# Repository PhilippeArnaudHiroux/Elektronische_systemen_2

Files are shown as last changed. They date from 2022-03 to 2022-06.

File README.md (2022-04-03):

# Elektronische_systemen_2

## Multisim

Lichtspectrum analyse sensor

1. **De onderdelen op de schakeling**
- XWG1 en XSC1 stellen de Esp32 voor
- U1 is de demultiplexer
- Q… zijn de fototransistors
- U… zijn invertors (zijn niet nodig op de PCB)
- R zijn de weerstanden die het licht voorstellen

1. **Hoe werkt de schakeling**
   1. *XWG1*

De XWG1 fungeert als een word generator. Deze gaat binaire getallen van 000 tot 111 uitsturen naar de demultiplexer. Dit is de output van de Esp32.



1. *De demultiplexer*

De demultiplexer gaat de binaire woorden van de word generator ontvangen op zijn 4 ingangen. Vervolgens gaat deze hiermee zijn uitgangen aansturen. Op elke uitgang is er een fototransistor aangesloten. 

1. *De invertors*

In Multisim hebben ze alleen demultiplexers die  die enkel laag uitstuurt zoals in de waarheidstabel zichtbaar is.

Daarom gebruiken we in onze schakeling invertors.
Maar de demultiplexer die we gaan gebruiken op de PCB heeft wel de juiste waarheidstabel, dus er komen geen invertors op de PCB.

1. *De fototransistors*

De fototransistors gaan de lichtintensiteit van elke kleur in het kleurenspectrum meten. Zij gaan een stroom doorlaten naar gelang van de intensiteit van het licht.
De fototransistors worden door de demultiplexer om de beurt aangestuurd. In de multisimschakeling gebruiken we gewone transistors, voor gemak van simulatie.

1. *De weerstanden*
   Op de Multisim schakeling stellen de weerstanden de lichtintensiteit voor. Elke weerstand heeft een andere waarden, dit is om het verschil in lichtintensiteit weer te geven.
1. *De XSC1*

Dit is de input van de Esp32, hier worden de waardes van de fototransistors terug ingelezen.
Op de foto kan je duidelijk zien dat er 8 verschillende waardes worden in gelezen. Als je de waarde van een weerstand aanpast gaat die waarde ook in de grafiek veranderen. Elke waarde staat voor een andere lichtintensiteit.

1. **Het programma laten werken**

Als je de oscilloscoop beeld open zet en dan de schakeling start dan werkt de schakeling. De waardes van de weetstanden kan je aanpassen om de schakeling meer in detail te testen.

1. **Bronnen**
   1. *Datasheet van de demultiplexer in Multisim
      <https://www.ti.com/lit/ds/sdls109/sdls109.pdf>* 
2

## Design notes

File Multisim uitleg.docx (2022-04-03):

1. De onderdelen op de schakeling
- XWG1 en XSC1 stellen de Esp32 voor
- U1 is de demultiplexer
- Q… zijn de fototransistors
- U… zijn invertors (zijn niet nodig op de PCB)
- R zijn de weerstanden die het licht voorstellen
2. Hoe werkt de schakeling
  I. XWG1

De XWG1 fungeert als een word generator. Deze gaat binaire getallen van 000 tot 111 uitsturen naar de demultiplexer. Dit is de output van de Esp32.

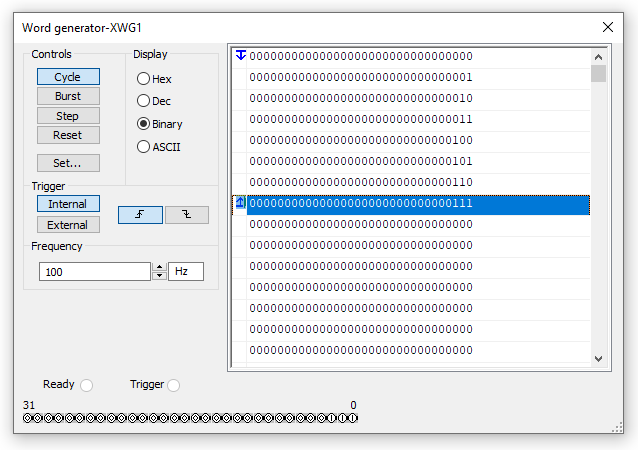
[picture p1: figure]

  II. De demultiplexer

De demultiplexer gaat de binaire woorden van de word generator ontvangen op zijn 4 ingangen. Vervolgens gaat deze hiermee zijn uitgangen aansturen. Op elke uitgang is er een fototransistor aangesloten.

  III. De invertors

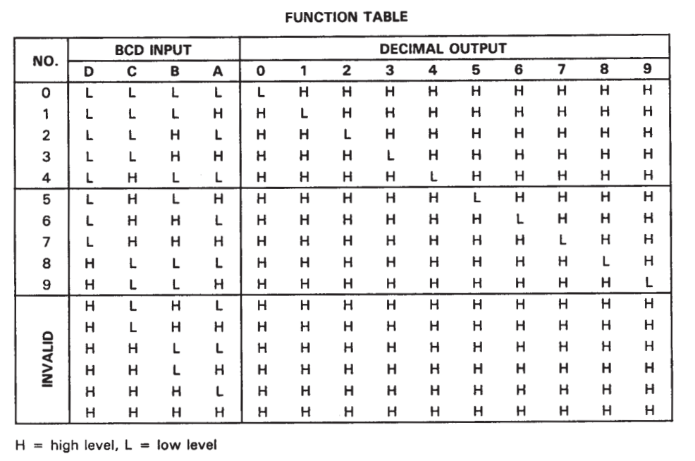
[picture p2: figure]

In Multisim hebben ze alleen demultiplexers die die enkel laag uitstuurt zoals in de waarheidstabel zichtbaar is.

Daarom gebruiken we in onze schakeling invertors.
Maar de demultiplexer die we gaan gebruiken op de PCB heeft wel de juiste waarheidstabel, dus er komen geen invertors op de PCB.

  IV. De fototransistors

De fototransistors gaan de lichtintensiteit van elke kleur in het kleurenspectrum meten. Zij gaan een stroom doorlaten naar gelang van de intensiteit van het licht.
De fototransistors worden door de demultiplexer om de beurt aangestuurd. In de multisimschakeling gebruiken we gewone transistors, voor gemak van simulatie.

  V. De weerstanden Op de Multisim schakeling stellen de weerstanden de lichtintensiteit voor. Elke weerstand heeft een andere waarden, dit is om het verschil in lichtintensiteit weer te geven.
  VI. De XSC1

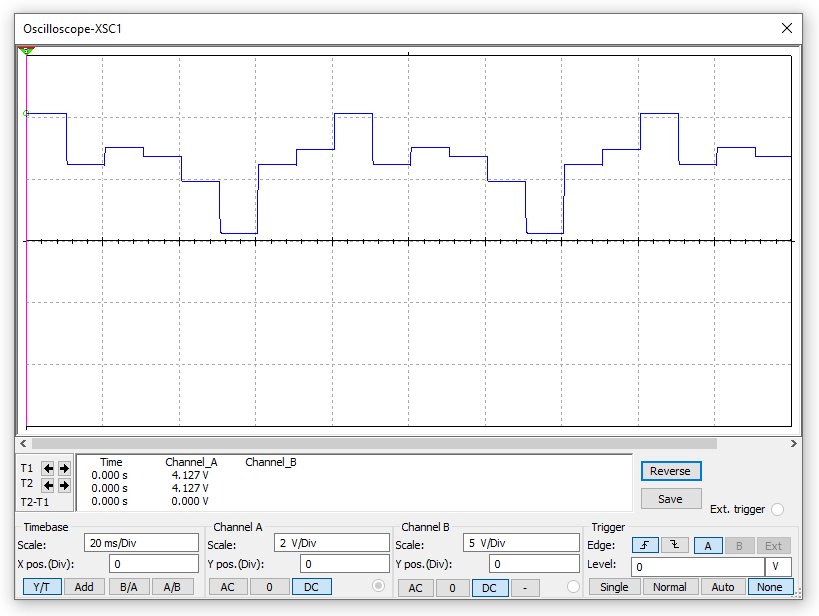
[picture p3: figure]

Dit is de input van de Esp32, hier worden de waardes van de fototransistors terug ingelezen.
Op de foto kan je duidelijk zien dat er 8 verschillende waardes worden in gelezen. Als je de waarde van een weerstand aanpast gaat die waarde ook in de grafiek veranderen. Elke waarde staat voor een andere lichtintensiteit.

3. Het programma laten werken

Als je de oscilloscoop beeld open zet en dan de schakeling start dan werkt de schakeling. De waardes van de weetstanden kan je aanpassen om de schakeling meer in detail te testen.

4. Bronnen
  I. Datasheet van de demultiplexer in Multisim https://www.ti.com/lit/ds/sdls109/sdls109.pdf

Lichtspectrum analyse sensor

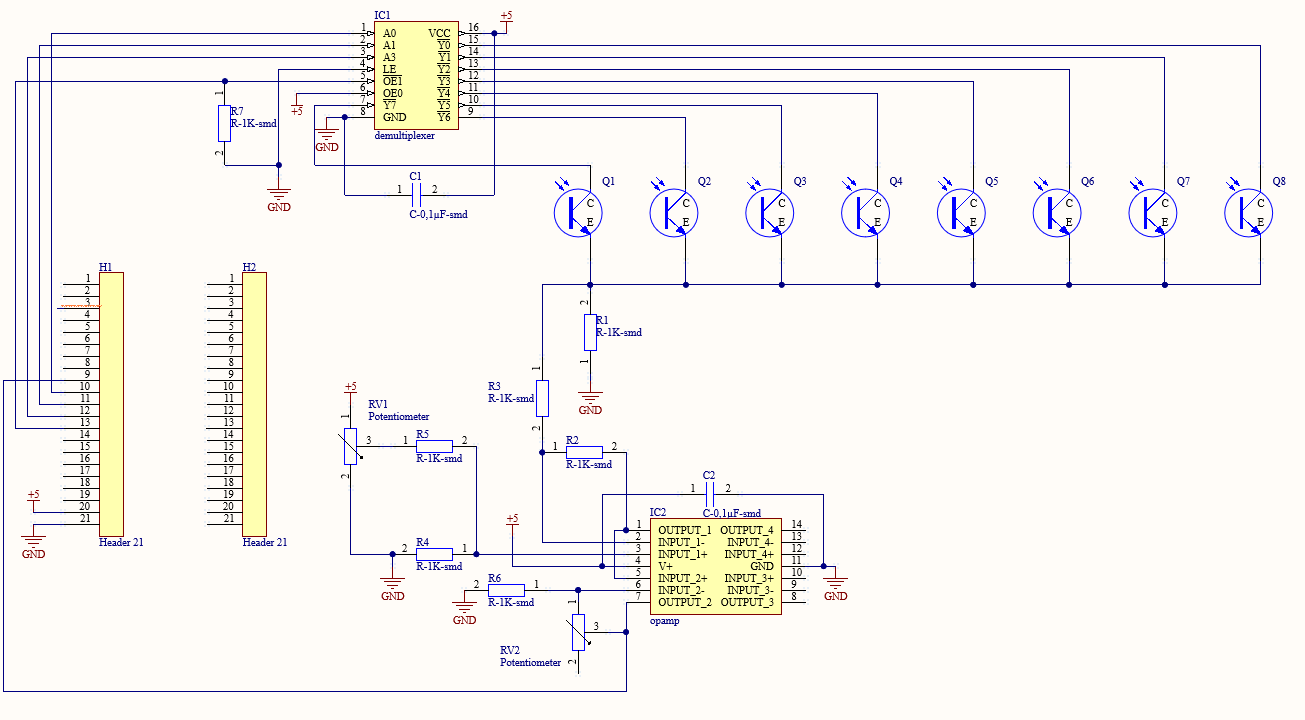
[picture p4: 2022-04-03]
img/scematic.png

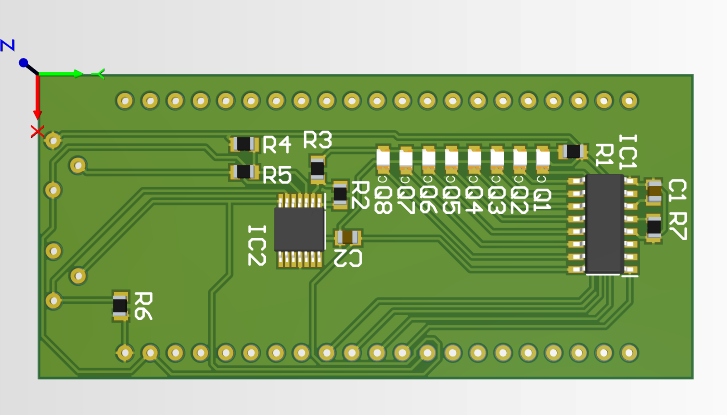
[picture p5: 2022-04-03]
img/pcb.png

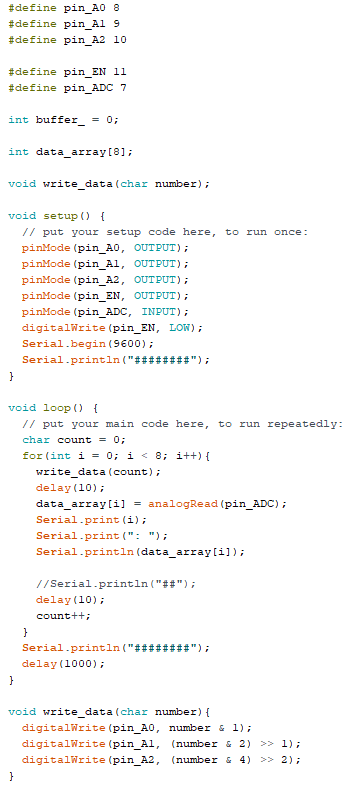
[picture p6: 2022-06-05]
AN/software_scr2.png

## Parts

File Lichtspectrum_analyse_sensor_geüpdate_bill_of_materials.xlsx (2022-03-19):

Aantal | Component | Verdeler | Website | Opmerkingen
2 | Demultiplexer: CD74HC237M | Mouser | https://eu.mouser.com/ProductDetail/Texas-Instruments/CD74HC237M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
1 | MCU: ESP32 | Mouser | https://eu.mouser.com/ProductDetail/Espressif-Systems/ESP32-S2-Saola-1R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
10 | Fototransistor: | Mouser | https://eu.mouser.com/ProductDetail/Wurth-Elektronik/1540801NBA300?qs=GedFDFLaBXH38ZWIf1jxBQ%3D%3D
2 | Opamp: LM2902MTX/NOPB | mouser | https://eu.mouser.com/ProductDetail/Texas-Instruments/LM2902MTX-NOPB?qs=X1J7HmVL2ZF2DaQj6Twcig%3D%3D
5 | Condensator: 100nF | Mouser | https://eu.mouser.com/ProductDetail/KEMET/C0805C104K5RAC7411?qs=jbRM9o5BbzPcVXF0wW9AYg%3D%3D
3 | Potentiometer: 10kohm | Mouser | https://eu.mouser.com/ProductDetail/Amphenol-Piher/PT10LH01-103A2020-S?qs=pCZPOPZMYPhaGxjxXoAF9g%3D%3D
10 | Resistor 1k | Mouser | https://eu.mouser.com/ProductDetail/YAGEO/RC0805FR-131KL?qs=sGAEpiMZZMtlubZbdhIBIHucEnbnlIRRSgPSrgMtIFk%3D | precisieweerstand voor stroommeting uit lichtsensor en differentiatie opamp

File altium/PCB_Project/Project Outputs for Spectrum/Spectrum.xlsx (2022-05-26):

Comment | Description | Designator | Footprint | LibRef | Quantity
C-0,1µF-smd | Capacitor | C1, C2 | C-0,1µF-smd | C-0,1µF-smd | 2
Header 21 |  | H1, H2 | Header 21 | Header 21 | 2
demultiplexer | Integrated Circuit | IC1 | demultiplexer | demultiplexer | 1
opamp | Integrated Circuit | IC2 | SOIC127P600X175-14N | opamp | 1
400-1100nm, 1mA, 130deg | WL-STCW SMT Phototransistor Chip Waterclear, size 0805, 400-1100nm, 1mA, 130deg | Q1, Q2, Q3, Q4, Q5, Q6, Q7, Q8 | WL-STCW_0805 | 1540801NBA300 | 8
R-1K-smd | Resistor | R1, R2, R3, R4, R5, R6, R7 | R-1K-smd | R-1K-smd | 7
Potentiometer | PT10LH01-104A2020-S | RV1, RV2 | Potentiometer | Potentiometer | 2

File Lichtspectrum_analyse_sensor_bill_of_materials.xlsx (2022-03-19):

Aantal | Component | Verdeler | Website
2 | Demultiplexer: CD74HC237M | Mouser | https://eu.mouser.com/ProductDetail/Texas-Instruments/CD74HC237M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
1 | MCU: arduino nano | Mouser | https://eu.mouser.com/ProductDetail/Arduino/ABX00028?qs=PzGy0jfpSMtit6rnFl8mVg%3D%3D
10 | Fototransistor: | Mouser | https://eu.mouser.com/ProductDetail/Wurth-Elektronik/1540801NBA300?qs=GedFDFLaBXH38ZWIf1jxBQ%3D%3D
2 | Opamp: LM2902MTX/NOPB | mouser | https://eu.mouser.com/ProductDetail/Texas-Instruments/LM2902MTX-NOPB?qs=X1J7HmVL2ZF2DaQj6Twcig%3D%3D
2 | Condensator: 100nF | Mouser | https://eu.mouser.com/ProductDetail/KEMET/C0805C104K5RAC7411?qs=jbRM9o5BbzPcVXF0wW9AYg%3D%3D
3 | Potentiometer: 100kohm | Mouser | https://eu.mouser.com/ProductDetail/Amphenol-Piher/PT10LH01-104A2020-S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

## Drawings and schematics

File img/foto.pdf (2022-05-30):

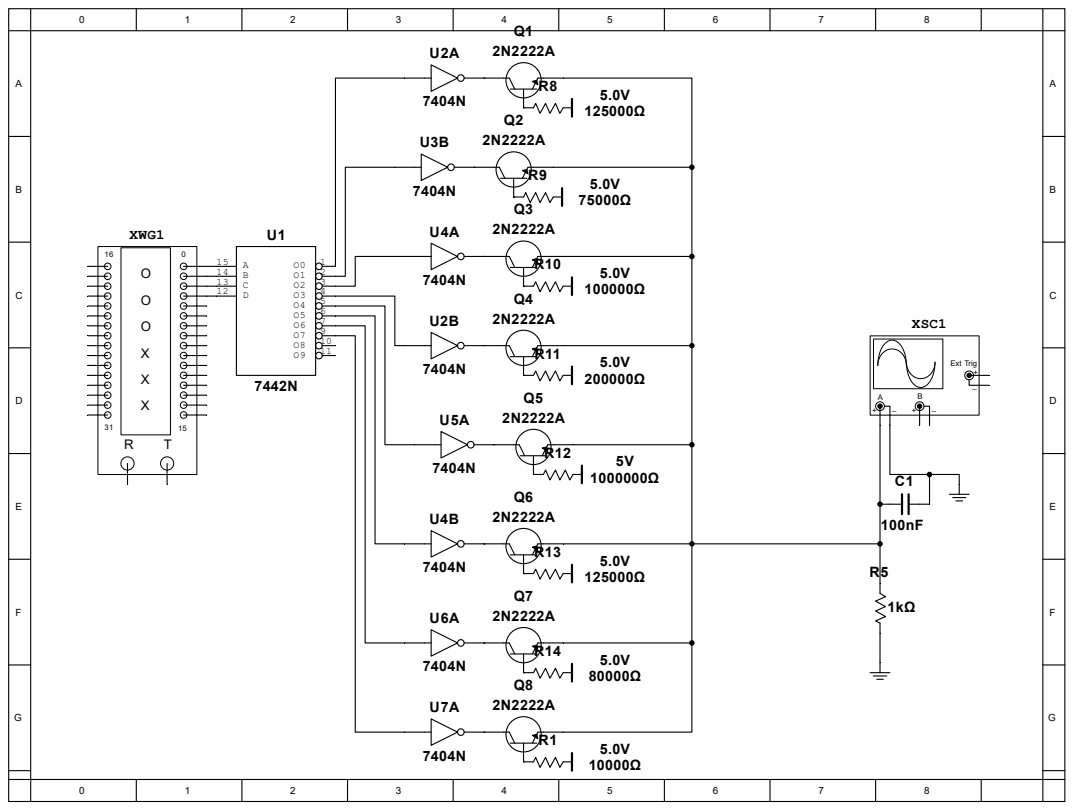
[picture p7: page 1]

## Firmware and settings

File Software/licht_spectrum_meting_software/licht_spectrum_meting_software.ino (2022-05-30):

#define pin_A0 8
#define pin_A1 9
#define pin_A2 10

#define pin_EN 11
#define pin_ADC 7

int buffer_ = 0;

int data_array[8];

void write_data(char number);

void setup() {
  // put your setup code here, to run once:
  pinMode(pin_A0, OUTPUT);
  pinMode(pin_A1, OUTPUT);
  pinMode(pin_A2, OUTPUT);
  pinMode(pin_EN, OUTPUT);
  pinMode(pin_ADC, INPUT);
  digitalWrite(pin_EN, LOW);
  Serial.begin(9600);
  Serial.println("########");
}

void loop() {
  // put your main code here, to run repeatedly:
  char count = 0;
  for(int i = 0; i < 8; i++){
    write_data(count);
    delay(10);
    data_array[i] = analogRead(pin_ADC);
    Serial.print(i);
    Serial.print(": ");
    Serial.println(data_array[i]);
    
    //Serial.println("##");
    delay(10);
    count++;
  }
  Serial.println("########");
  delay(1000);
}

void write_data(char number){
  digitalWrite(pin_A0, number & 1);
  digitalWrite(pin_A1, (number & 2) >> 1);
  digitalWrite(pin_A2, (number & 4) >> 2);
}

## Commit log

2022-03-21 Altium libarys
    [PcbLib1.PcbLib, Project_Libary.PcbLib, Project_Libary.SchLib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]
2022-03-21 ll
    ll
    [Sheet1.SchDoc]
2022-03-23 Altium vooruitgang 22/03
    [PCB1.PcbDoc, Project_Libary.PcbLib, Project_Libary.SchLib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]
2022-03-29 PCB GP
    [PCB1.PcbDoc, PCB2.PcbDoc, Sheet1.SchDoc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]
2022-03-30 groundplane fix
    [PCB2.PcbDoc]
2022-04-03 kleine edits
    [PCB1.PcbDoc, Spectrum.PrjPcb]
2022-04-26 footprint edit
    [PCB2.PcbDoc, Project_Libary.PcbLib, Sheet1.SchDoc]
2022-04-29 PCB edit
    [PCB2.PcbDoc, Project_Libary.PcbLib]
2022-05-26 esp32 code
2022-05-30 update
    Zeg esp 32 S2 een paar keer
2022-05-30 uart code edit
